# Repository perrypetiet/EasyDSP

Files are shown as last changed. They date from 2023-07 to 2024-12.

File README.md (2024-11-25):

# EasyDSP prototype_dev v0.1 development branch.
This is the EasyDSP prototype development library. In this repository you will find the hardware of the EasyDSP as well as the corresponding firmware. In this readme you will find an explanation of how to firmware functions and how to control the EasyDSP using the corresponding communication protocol. Also, you will find the PCB schematics and PCB design without the need to have KiCad and all the corresponding components on hand.

This readme will be updated to display correct and relevant information depending on the branch.

## Table of contents:
- [EasyDSP prototype\_dev v0.1 development branch.](#easydsp-prototype_dev-v01-development-branch)
  - [Table of contents:](#table-of-contents)
  - [Introduction ](#introduction-)
  - [TODO list ](#todo-list-)
  - [Controlling via BLE. ](#controlling-via-ble-)
  - [Python. ](#python-)
  - [Hardware ](#hardware-)

## Introduction 
The goal of this project is to make a cheap and easy to control module in order to do all your audio digital signal processing needs. The EasyDSP could be used for audio crossover, room correction, subwoofer tuning, using [Bass Eq](https://www.avsforum.com/threads/bass-eq-for-filtered-movies.2995212/) and much more. The goal of the project is to be able to control the EasyDSP using a Bluetooth low energy connection. When connected BLE characteristics can be used to control the EasyDSP. The basic structure of the signal processor can be explained with the following image:
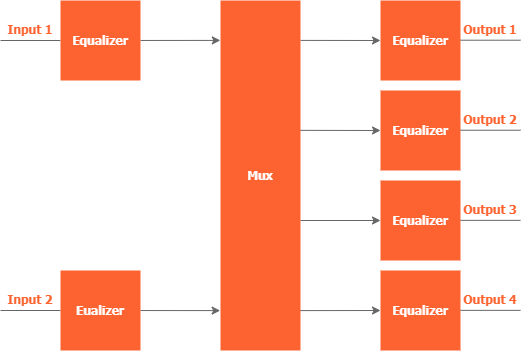
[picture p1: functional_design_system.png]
Basic DSP overview
</br></br>
The EasyDSP has two inputs and four outputs. The mux makes it possible to connect any input with any output. Every in and output has an equalizer to which five filters can be applied.</br>
The goal of the protoype is to implement the basic functioning of this system while doing it reliably. When this is achieved, functionality can be upgraded.

## TODO list 

- Make the settings store on the EEPROM. ✅
- Implement more filters (Bessel?) for better low pass and high pass.
- Maybe improve Python module for this verstion.

Things to include in next version:
- Better PCB design to improve the noise in the audio signal coming from the Bluetooth antenna (External antenna?).
- RGB status indication LED.
- Case design. (3D printable).
- Start working on GUI app for desktop to control the device.
- More functionality in firmware, more filters and gain control. And overall cleanup. 
- Thinking about serial control via USB.

## Controlling via BLE. 
Easydsp can be controlled with a BLE connection. The BLE implements two different services. The first service is a "selection" service. With this service the channel and eq number that are desired to be changed can be selected. With the channel number characteriscic you can change the channel number. With the isOutput characteristic you can select if it is an input or output channel that is selected. With the eq characteristic you can selected one of the 5 eq's per channel that you wish to change te settings of.

The EQ service implements the EQ data of the selected EQ on the selected channel. This service has characteristics to change the behaviour of the selected EQ. 

## Python. 
Included is a simple python module, easydsp.py, that can be used to control the easydsp over a BLE connection. I have also included a simple Python command line program that uses this module to control the EasyDSP.

## Hardware 
The EasyDSP is based on the ADAU1701 digital signal processor from Analog Devices. The chip is used in I2C control mode. This way, we can control the the signal processor from an external microcontroller during operation. The microcontroller used is an ESP32-S3 in the form a WROOM module to make development of the prototype hardware easier. The board and firmware have the ability to store the EQ, MUX and gain settings on an EEPROM. The EEPROM used is a 24LC128 in an MSOP package. Technically lower storage 24LC EEPROM's can also be used. In order to upload the firmware to the board, the USB connector on the PCB can be used. Firmware can also be uploaded and monitored using an external USB to UART PCB connected to the connector on the main PCB. There is an example board in the hardware folder. Following is the hardware schematic. The schematic can also be opened using KiCad.
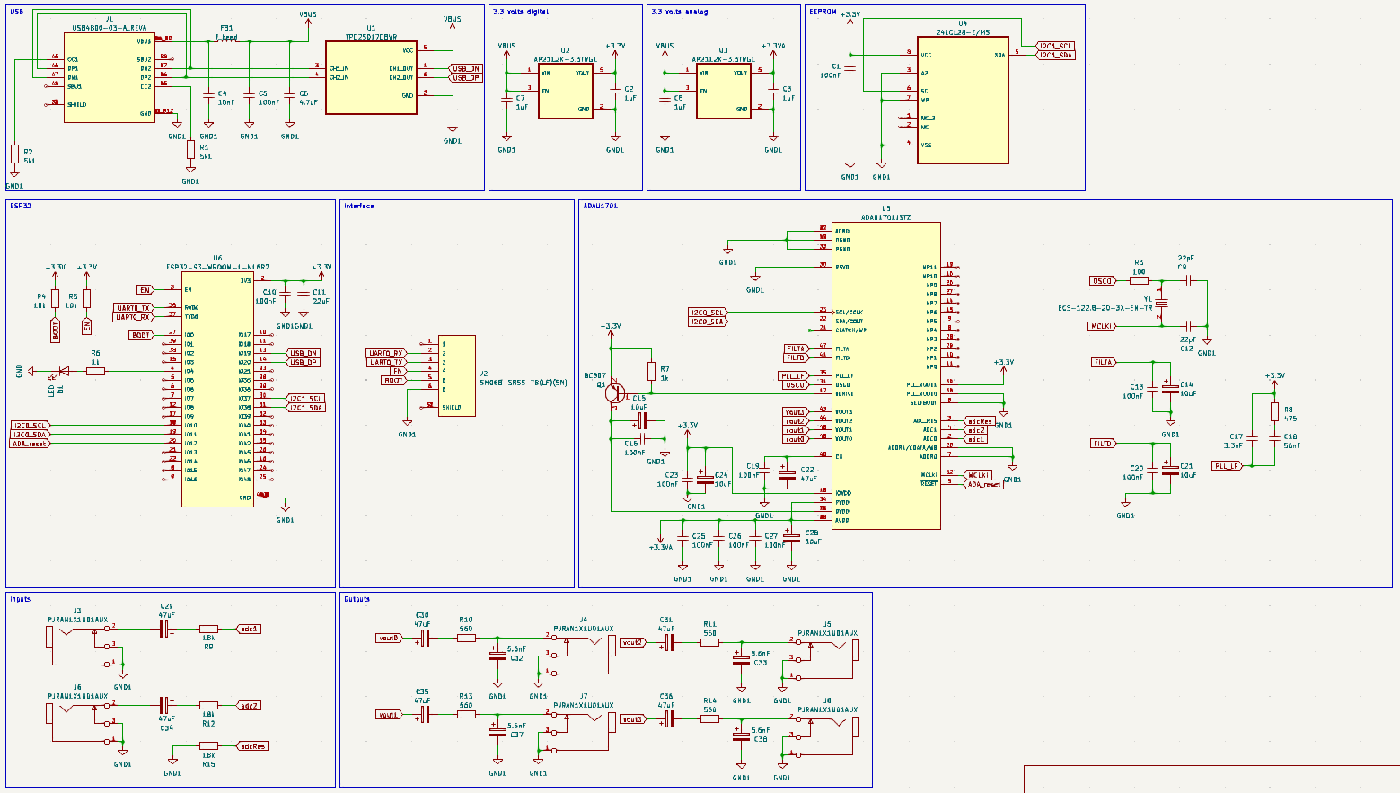
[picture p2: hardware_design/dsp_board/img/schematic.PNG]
Hardware schematic
</br></br>
The PCB fabrication files can be found in the hardware_design folder. Using these gerber and drill files you can order a PCB from a manufactorer.
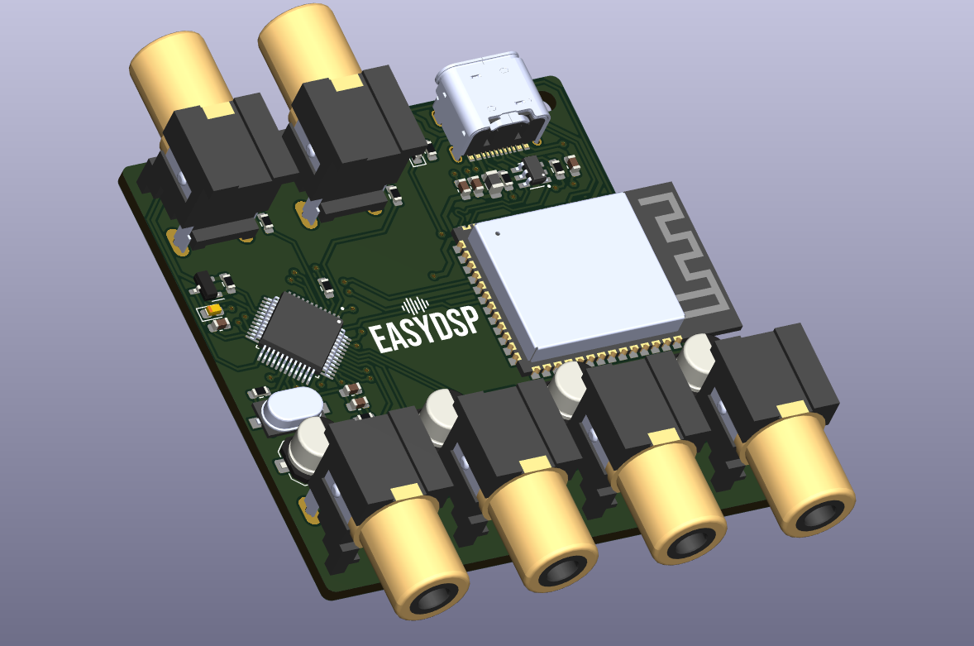
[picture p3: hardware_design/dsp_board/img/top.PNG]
PCB top
</br></br>
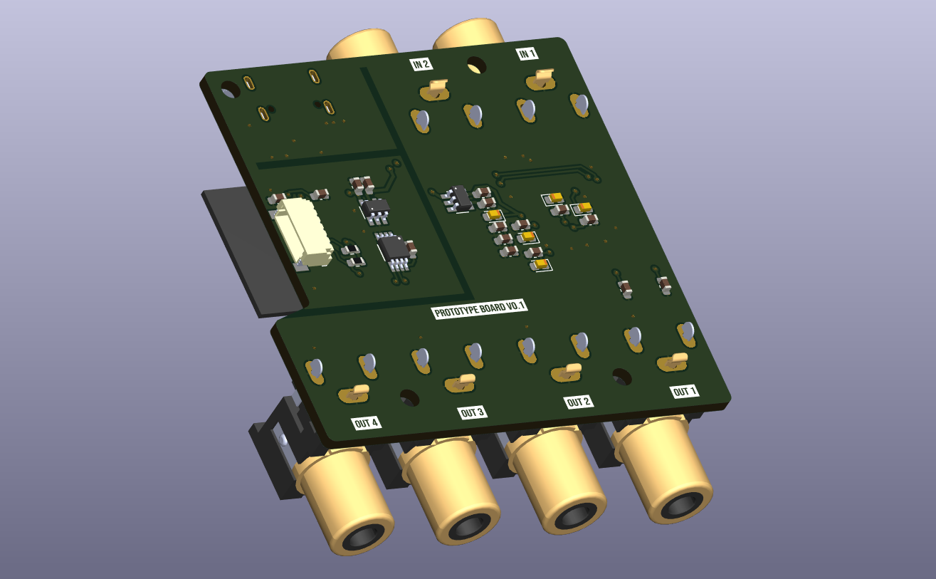
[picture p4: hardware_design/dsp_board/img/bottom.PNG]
PCB bottom
</br></br>

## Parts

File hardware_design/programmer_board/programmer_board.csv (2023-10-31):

# | Reference | Qty | Value | Footprint | DNP
1 | C1, C2 | 2 | 1uF | Capacitor_SMD:C_0603_1608Metric
2 | C3, C4 | 2 | 22pF | Capacitor_SMD:C_0603_1608Metric
3 | C5 | 1 | 10nF | Capacitor_SMD:C_0603_1608Metric
4 | C6, C8, C9 | 3 | 100nF | Capacitor_SMD:C_0603_1608Metric
5 | C7 | 1 | 4.7uF | Capacitor_SMD:C_0603_1608Metric
6 | D1 | 1 | LED | Diode_SMD:D_0603_1608Metric
7 | FB1 | 1 | f_bead | Inductor_SMD:L_0805_2012Metric
8 | J1 | 1 | SM06B-SRSS-TB(LF)(SN) | JST_SM06B-SRSS-TB(LF)(SN)
9 | J2 | 1 | USB4800-03-A_REVA | GCT_USB4800-03-A_REVA
10 | Q1, Q2 | 2 | SS8050-G | TRANS_SS8050-G
11 | R1 | 1 | 0 | Resistor_SMD:R_0603_1608Metric
12 | R2, R4 | 2 | 10k | Resistor_SMD:R_0603_1608Metric
13 | R3, R5, R6 | 3 | 5k1 | Resistor_SMD:R_0603_1608Metric
14 | S1, S2 | 2 | TL6330AF200Q | SW_TL6330AF200Q
15 | U1 | 1 | AP2112K-3.3TRG1 | SOT95P285X140-5N
16 | U2 | 1 | TPD2S017DBVR | SOT95P280X145-6N
17 | U3 | 1 | CH340G | SOIC127P600X180-16N
18 | Y1 | 1 | ECS-120-20-3X-EN-TR | XTAL_ECS-120-20-3X-EN-TR

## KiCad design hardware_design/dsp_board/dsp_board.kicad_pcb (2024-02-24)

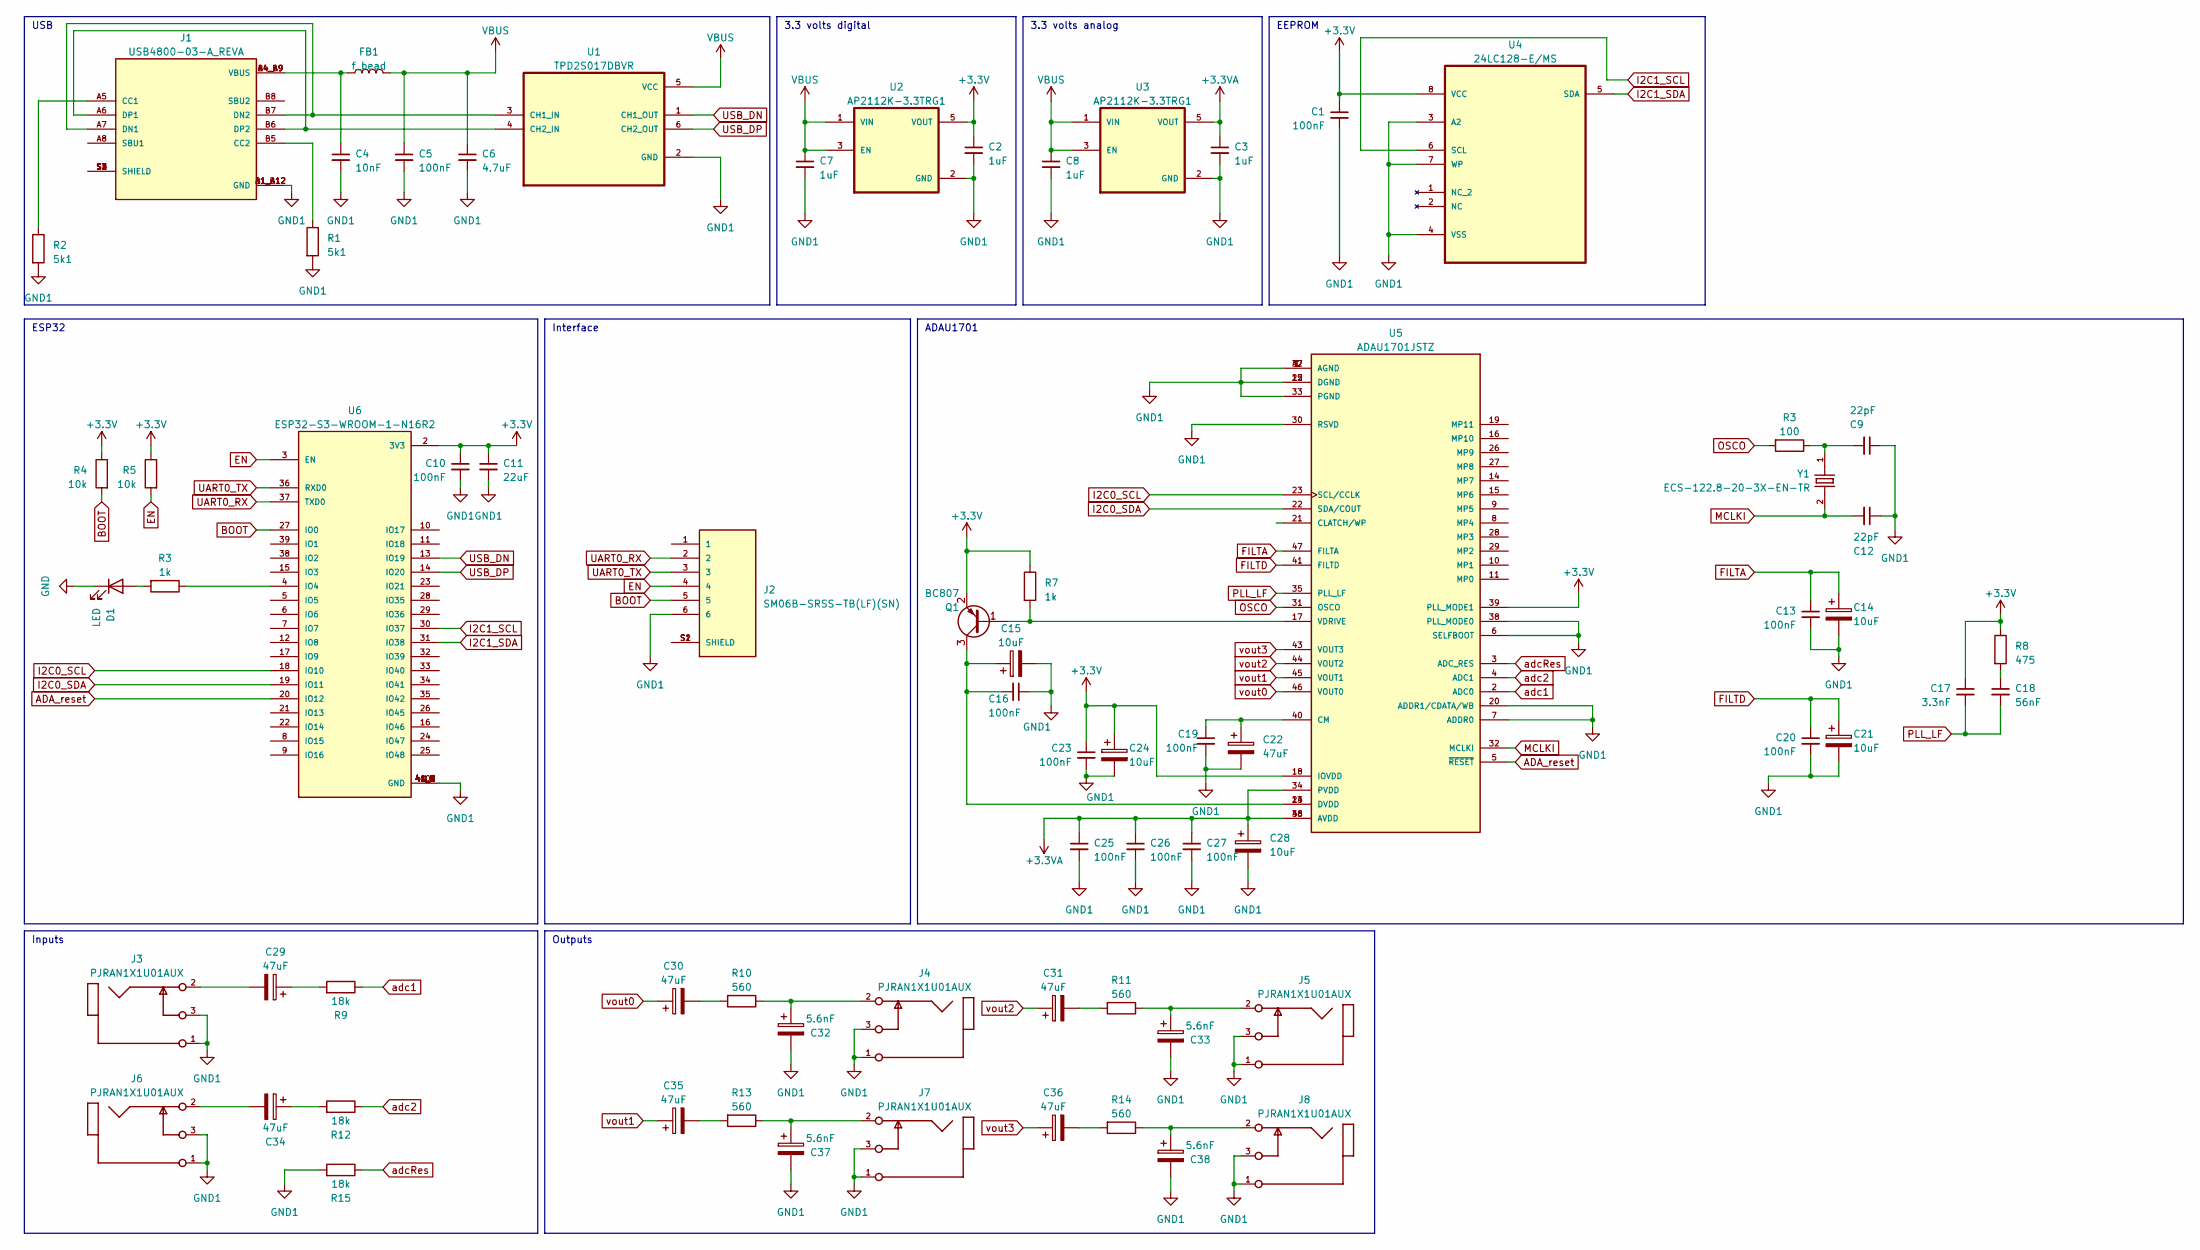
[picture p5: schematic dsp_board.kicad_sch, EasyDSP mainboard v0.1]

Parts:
C1, C5, C10, C13, C16, C19, C20, C23, C25, C26, C27: 100nF; C_0603_1608Metric
C2, C3, C7, C8: 1uF; C_0603_1608Metric
C4: 10nF; C_0603_1608Metric
C6: 4.7uF; C_0603_1608Metric
C9, C12: 22pF; C_0603_1608Metric
C11: 22uF; C_0603_1608Metric
C14, C15, C21, C24, C28: 10uF; CP_EIA-1608-08_AVX-J
C17: 3.3nF; C_0603_1608Metric
C18: 56nF; C_0603_1608Metric
C22, C29, C34: 47uF; CP_EIA-1608-08_AVX-J
C30, C31, C35, C36: 47uF; CP_Elec_5x4.5
C32, C33, C37, C38: 5.6nF; CP_EIA-1608-08_AVX-J
D1: LED; D_0603_1608Metric
FB1: f_bead; L_0805_2012Metric
J1: USB4800-03-A_REVA; GCT_USB4800-03-A_REVA; PARTREV A
J2: SM06B-SRSS-TB(LF)(SN); JST_SM06B-SRSS-TB(LF)(SN)
J3, J4, J5, J6, J7, J8: PJRAN1X1U01AUX; PJRAN1X1U01X
Q1: BC807; SOT-23
R1, R2: 5k1; R_0603_1608Metric
R3: 100; R_0603_1608Metric
R4, R5: 10k; R_0603_1608Metric
R7: 1k; R_0603_1608Metric
R8: 475; R_0603_1608Metric
R9, R12, R15: 18k; R_0603_1608Metric
R10, R11, R13, R14: 560; R_0603_1608Metric
U1: TPD2S017DBVR; SOT95P280X145-6N
U2, U3: AP2112K-3.3TRG1; SOT95P285X140-5N; PARTREV 2-2
U4: 24LC128-E/MS; SOP65P490X110-8N; MPN 24LC128-E/MS
U5: ADAU1701JSTZ; QFP50P900X900X160-48N; PARTREV C
U6: ESP32-S3-WROOM-1-N16R2; XCVR_ESP32-S3-WROOM-1-N16R2; PARTREV v1.0
Y1: ECS-122.8-20-3X-EN-TR; XTAL_ECS-122.8-20-3X-EN-TR; PARTREV 2017

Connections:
+3.3V: C1.1, C2.1, C10.1, C11.1, C17.1, C23.1, C24.1, Q1.2 (E), R4.1, R5.1, R7.1, R8.1, U2.5 (VOUT), U4.8 (VCC), U5.18 (IOVDD), U5.39 (PLL_MODE1), U6.2 (3V3)
+3.3VA: C3.1, C25.1, C26.1, C27.1, C28.1, U3.5 (VOUT), U5.34 (PVDD), U5.36 (AVDD), U5.48 (AVDD)
ADA_reset: U5.5 (~RESET), U6.20 (IO12)
BOOT: J2.5, R4.2, U6.27 (IO0)
EN: J2.4, R5.2, U6.3 (EN)
FILTA: C13.1, C14.1, U5.47 (FILTA)
FILTD: C20.1, C21.1, U5.41 (FILTD)
GND: D1.1 (K)
GND1: C1.2, C2.2, C3.2, C4.2, C5.2, C6.2, C7.2, C8.2, C9.1, C10.2, C11.2, C12.1, C13.2, C14.2, C15.2, C16.1, C19.2, C20.2, C21.2, C22.2, C23.2, C24.2, C25.2, C26.2, C27.2, C28.2, C32.2, C33.2, C37.2, C38.2, J1.A1_B12 (GND), J1.B1_A12 (GND), J2.6, J3.1, J3.3, J4.1, J4.3, J5.1, J5.3, J6.1, J6.3, J7.1, J7.3, J8.1, J8.3, R1.2, R2.2, R15.2, U1.2 (GND), U2.2 (GND), U3.2 (GND), U4.3 (A2), U4.4 (VSS), U4.7 (WP), U5.1 (AGND), U5.6 (SELFBOOT), U5.7 (ADDR0), U5.12 (DGND), U5.20 (ADDR1/CDATA/WB), U5.25 (DGND), U5.30 (RSVD), U5.33 (PGND), U5.37 (AGND), U5.38 (PLL_MODE0), U5.42 (AGND), U6.1 (GND), U6.40 (GND), U6.41_1 (GND), U6.41_2 (GND), U6.41_3 (GND), U6.41_4 (GND), U6.41_5 (GND), U6.41_6 (GND), U6.41_7 (GND), U6.41_8 (GND), U6.41_9 (GND)
I2C0_SCL: U5.23 (SCL/CCLK), U6.18 (IO10)
I2C0_SDA: U5.22 (SDA/COUT), U6.19 (IO11)
I2C1_SCL: U4.6 (SCL), U6.30 (IO37)
I2C1_SDA: U4.5 (SDA), U6.31 (IO38)
MCLKI: C12.2, U5.32 (MCLKI), Y1.2
unnamed: C4.1, FB1.1, J1.A4_B9 (VBUS), J1.B4_A9 (VBUS)
unnamed: C18.1, R8.2
unnamed: C29.1, R9.2
unnamed: C29.2, J3.2
unnamed: C30.2, R10.2
unnamed: C31.2, R11.2
unnamed: C32.1, J4.2, R10.1
unnamed: C33.1, J5.2, R11.1
unnamed: C34.1, R12.2
unnamed: C34.2, J6.2
unnamed: C35.2, R13.2
unnamed: C36.2, R14.2
unnamed: C37.1, J7.2, R13.1
unnamed: C38.1, J8.2, R14.1
unnamed: J1.A5 (CC1), R2.1
unnamed: J1.B5 (CC2), R1.1
unnamed: J1.A7 (DN1), J1.B7 (DN2), U1.3 (CH1_IN)
unnamed: J1.A6 (DP1), J1.B6 (DP2), U1.4 (CH2_IN)
unnamed: J1.S1 (SHIELD), J1.S2 (SHIELD), J1.S3 (SHIELD), J1.S4 (SHIELD)
unnamed: J2.S1 (SHIELD), J2.S2 (SHIELD)
unnamed: Q1.1 (B), R7.2, U5.17 (VDRIVE)
unnamed: C15.1, C16.2, Q1.3 (C), U5.13 (DVDD), U5.24 (DVDD)
unnamed: C19.1, C22.1, U5.40 (CM)
PLL_LF: C17.2, C18.2, U5.35 (PLL_LF)
UART0_RX: J2.2, U6.37 (TXD0)
UART0_TX: J2.3, U6.36 (RXD0)
USB_DN: U1.1 (CH1_OUT), U6.13 (IO19)
USB_DP: U1.6 (CH2_OUT), U6.14 (IO20)
VBUS: C5.1, C6.1, C7.1, C8.1, FB1.2, U1.5 (VCC), U2.1 (VIN), U2.3 (EN), U3.1 (VIN), U3.3 (EN)
adc1: R9.1, U5.2 (ADC0)
adc2: R12.1, U5.4 (ADC1)
adcRes: R15.1, U5.3 (ADC_RES)
vout0: C30.1, U5.46 (VOUT0)
vout1: C35.1, U5.45 (VOUT1)
vout2: C31.1, U5.44 (VOUT2)
vout3: C36.1, U5.43 (VOUT3)

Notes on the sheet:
Interface
Inputs
Outputs
ADAU1701
3.3 volts analog
3.3 volts digital
EEPROM
ESP32
USB

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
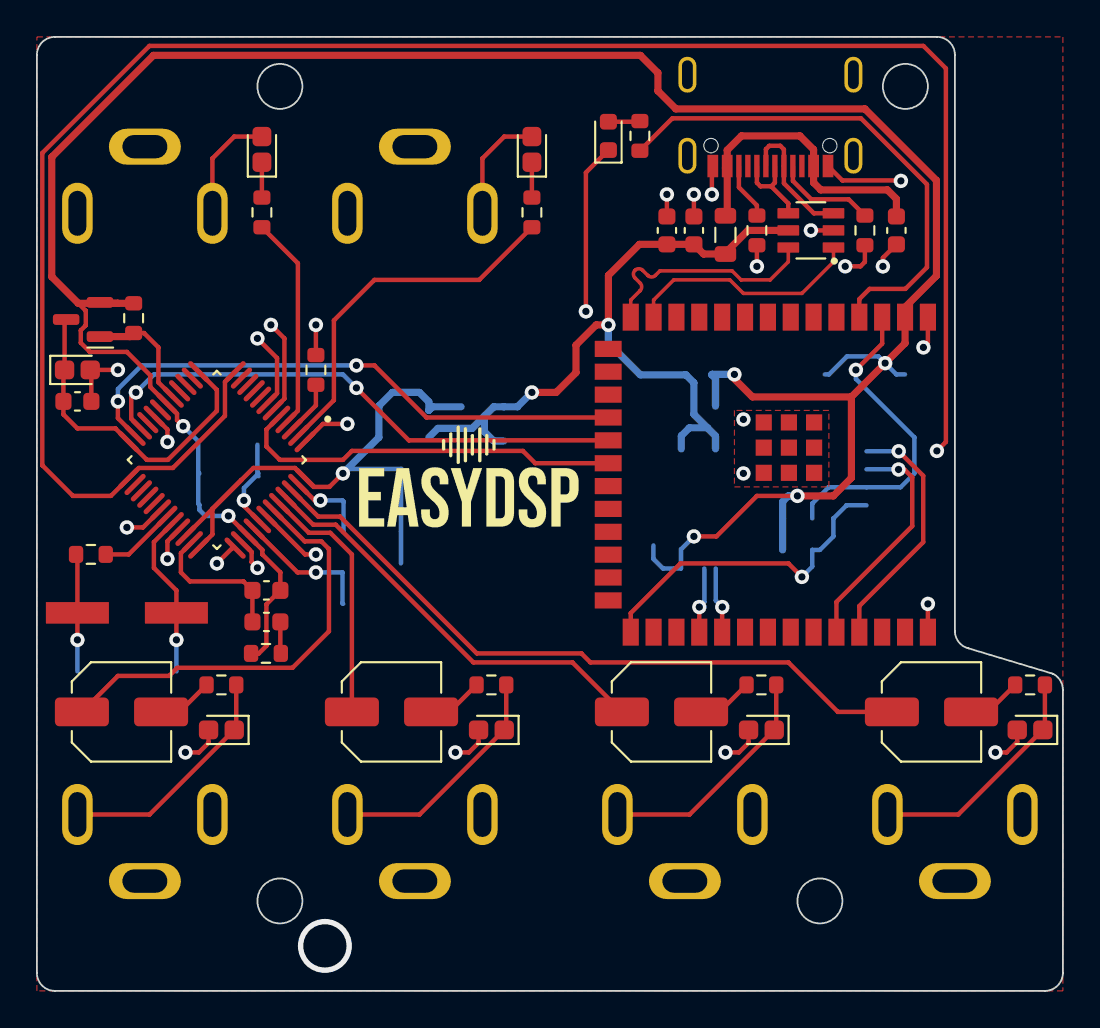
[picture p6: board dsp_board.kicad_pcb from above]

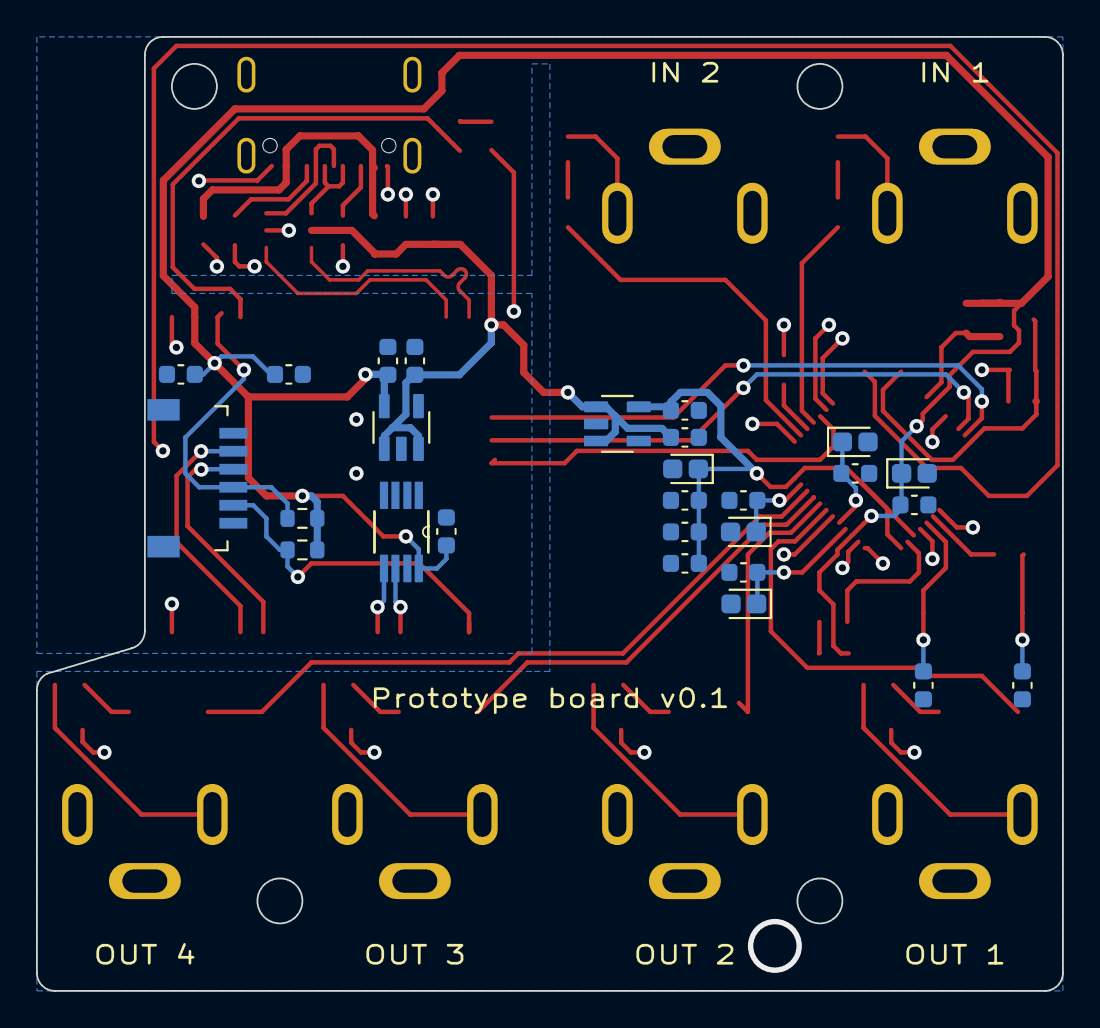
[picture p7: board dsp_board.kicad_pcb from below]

Board: 2 copper layers, 57.0 x 53.0 mm, 71 parts (27 on the bottom side), 53 nets.

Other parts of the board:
R6: 1k; R_0603_1608Metric

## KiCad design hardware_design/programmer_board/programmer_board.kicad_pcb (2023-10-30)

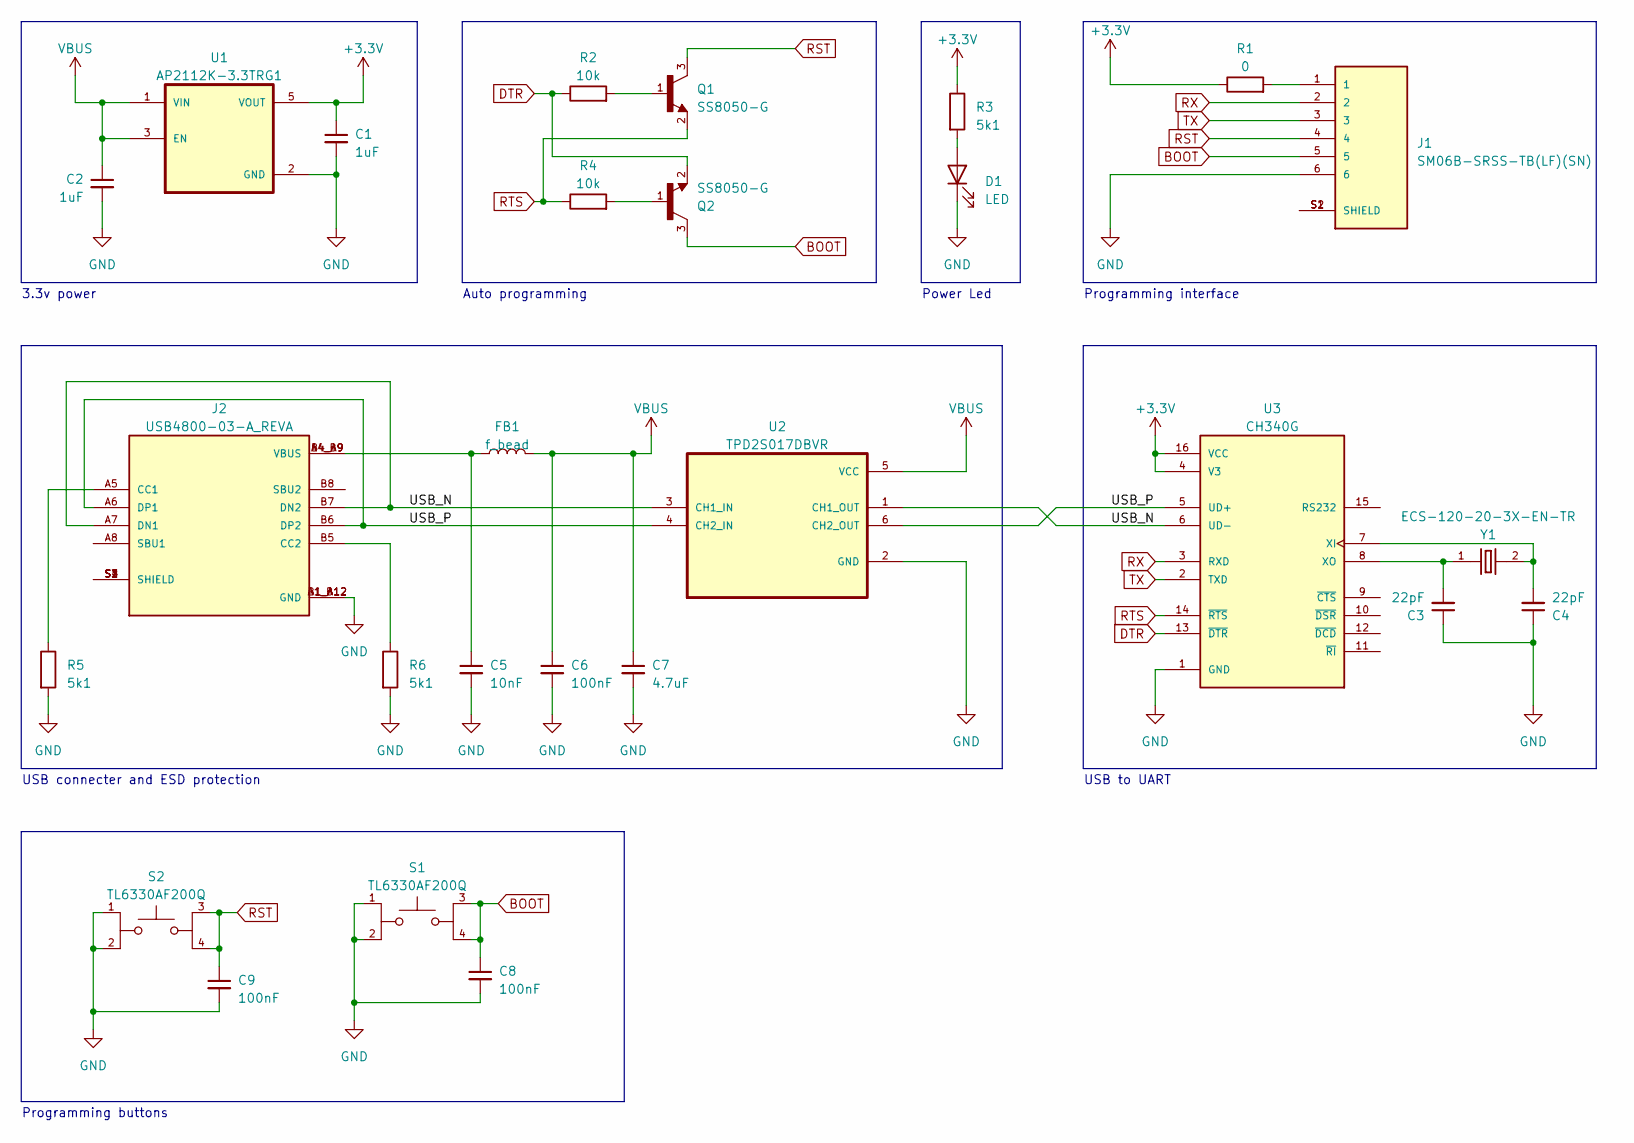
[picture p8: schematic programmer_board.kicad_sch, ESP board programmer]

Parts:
C1, C2: 1uF; C_0603_1608Metric
C3, C4: 22pF; C_0603_1608Metric
C5: 10nF; C_0603_1608Metric
C6, C8, C9: 100nF; C_0603_1608Metric
C7: 4.7uF; C_0603_1608Metric
D1: LED; D_0603_1608Metric
FB1: f_bead; L_0805_2012Metric
J1: SM06B-SRSS-TB(LF)(SN); JST_SM06B-SRSS-TB(LF)(SN)
J2: USB4800-03-A_REVA; GCT_USB4800-03-A_REVA; PARTREV A
Q1, Q2: SS8050-G; TRANS_SS8050-G; PARTREV A
R1: 0; R_0603_1608Metric
R2, R4: 10k; R_0603_1608Metric
R3, R5, R6: 5k1; R_0603_1608Metric
S1, S2: TL6330AF200Q; SW_TL6330AF200Q; PARTREV D
U1: AP2112K-3.3TRG1; SOT95P285X140-5N; PARTREV 2-2
U2: TPD2S017DBVR; SOT95P280X145-6N
U3: CH340G; SOIC127P600X180-16N; PARTREV 2G
Y1: ECS-120-20-3X-EN-TR; XTAL_ECS-120-20-3X-EN-TR; PARTREV 2017

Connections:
+3.3V: C1.1, R1.1, R3.1, U1.5 (VOUT), U3.4 (V3), U3.16 (VCC)
/USB_N: J2.A7 (DN1), J2.B7 (DN2), U2.1 (CH1_OUT), U2.3 (CH1_IN), U3.6 (UD-)
/USB_P: J2.A6 (DP1), J2.B6 (DP2), U2.4 (CH2_IN), U2.6 (CH2_OUT), U3.5 (UD+)
BOOT: C8.1, J1.5, Q2.3, S1.3, S1.4
DTR: Q2.2, R2.1, U3.13 (~DTR)
GND: C1.2, C2.2, C3.1, C4.1, C5.2, C6.2, C7.2, C8.2, C9.2, D1.1 (K), J1.6, J2.A1_B12 (GND), J2.B1_A12 (GND), R5.2, R6.2, S1.1, S1.2, S2.1, S2.2, U1.2 (GND), U2.2 (GND), U3.1 (GND)
unnamed: C5.1, FB1.1, J2.A4_B9 (VBUS), J2.B4_A9 (VBUS)
unnamed: D1.2 (A), R3.2
unnamed: J1.1, R1.2
unnamed: J1.S1 (SHIELD), J1.S2 (SHIELD)
unnamed: J2.A5 (CC1), R5.1
unnamed: J2.B5 (CC2), R6.1
unnamed: J2.S1 (SHIELD), J2.S2 (SHIELD), J2.S3 (SHIELD), J2.S4 (SHIELD)
unnamed: Q1.1, R2.2
unnamed: Q2.1, R4.2
unnamed: C4.2, U3.7 (XI), Y1.2
unnamed: C3.2, U3.8 (XO), Y1.1
RST: C9.1, J1.4, Q1.3, S2.3, S2.4
RTS: Q1.2, R4.1, U3.14 (~RTS)
RX: J1.2, U3.3 (RXD)
TX: J1.3, U3.2 (TXD)
VBUS: C2.1, C6.1, C7.1, FB1.2, U1.1 (VIN), U1.3 (EN), U2.5 (VCC)

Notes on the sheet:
3.3v power
Programming interface
Auto programming
USB to UART
USB connecter and ESD protection
Programming buttons
Power Led

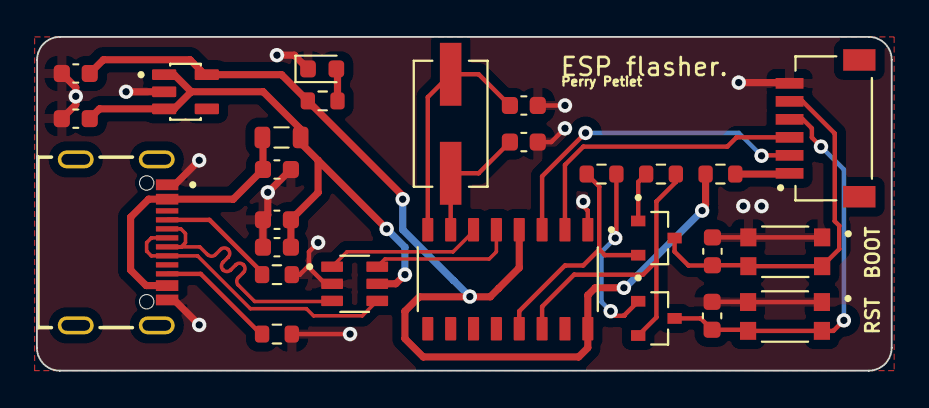
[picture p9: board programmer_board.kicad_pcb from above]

Board: 2 copper layers, 47.5 x 18.5 mm, 27 parts (0 on the bottom side), 22 nets.

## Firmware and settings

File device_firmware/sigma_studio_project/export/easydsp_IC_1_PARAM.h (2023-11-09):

/*
 * File:           C:\Users\perry\Documents\GitHub\EasyDSP\device_firmware\sigma_studio_project\export\easydsp_IC_1_PARAM.h
 *
 * Created:        Thursday, November 9, 2023 1:23:58 PM
 * Description:    easydsp:IC 1 parameter RAM definitions.
 *
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
 * This software may only be used to program products purchased from
 * Analog Devices for incorporation by you into audio products that
 * are intended for resale to audio product end users. This software
 * may not be distributed whole or in any part to third parties.
 *
 * Copyright ©2023 Analog Devices, Inc. All rights reserved.
 */
#ifndef __EASYDSP_IC_1_PARAM_H__
#define __EASYDSP_IC_1_PARAM_H__


/* Module input1_eq - Medium Size Eq*/
#define MOD_INPUT1_EQ_COUNT                            25
#define MOD_INPUT1_EQ_DEVICE                           "IC1"
#define MOD_INPUT1_EQ_ALG0_STAGE0_B0_ADDR              0
#define MOD_INPUT1_EQ_ALG0_STAGE0_B0_FIXPT             0x00800000
#define MOD_INPUT1_EQ_ALG0_STAGE0_B0_VALUE             SIGMASTUDIOTYPE_FIXPOINT_CONVERT(1)
#define MOD_INPUT1_EQ_ALG0_STAGE0_B0_TYPE              SIGMASTUDIOTYPE_FIXPOINT
#define MOD_INPUT1_EQ_ALG0_STAGE0_B1_ADDR              1
#define MOD_INPUT1_EQ_ALG0_STAGE0_B1_FIXPT             0x00000000
#define MOD_INPUT1_EQ_ALG0_STAGE0_B1_VALUE             SIGMASTUDIOTYPE_FIXPOINT_CONVERT(0)
#define MOD_INPUT1_EQ_ALG0_STAGE0_B1_TYPE              SIGMASTUDIOTYPE_FIXPOINT
#define MOD_INPUT1_EQ_ALG0_STAGE0_B2_ADDR              2
#define MOD_INPUT1_EQ_ALG0_STAGE0_B2_FIXPT             0x00000000
#define MOD_INPUT1_EQ_ALG0_STAGE0_B2_VALUE             SIGMASTUDIOTYPE_FIXPOINT_CONVERT(0)
#define MOD_INPUT1_EQ_ALG0_STAGE0_B2_TYPE              SIGMASTUDIOTYPE_FIXPOINT
#define MOD_INPUT1_EQ_ALG0_STAGE0_A0_ADDR              3
#define MOD_INPUT1_EQ_ALG0_STAGE0_A0_FIXPT             0x00000000
#define MOD_INPUT1_EQ_ALG0_STAGE0_A0_VALUE             SIGMASTUDIOTYPE_FIXPOINT_CONVERT(0)
#define MOD_INPUT1_EQ_ALG0_STAGE0_A0_TYPE              SIGMASTUDIOTYPE_FIXPOINT
#define MOD_INPUT1_EQ_ALG0_STAGE0_A1_ADDR              4
#define MOD_INPUT1_EQ_ALG0_STAGE0_A1_FIXPT             0x00000000
#define MOD_INPUT1_EQ_ALG0_STAGE0_A1_VALUE             SIGMASTUDIOTYPE_FIXPOINT_CONVERT(0)
#define MOD_INPUT1_EQ_ALG0_STAGE0_A1_TYPE              SIGMASTUDIOTYPE_FIXPOINT
#define MOD_INPUT1_EQ_ALG0_STAGE1_B0_ADDR              5
#define MOD_INPUT1_EQ_ALG0_STAGE1_B0_FIXPT             0x00800000
#define MOD_INPUT1_EQ_ALG0_STAGE1_B0_VALUE             SIGMASTUDIOTYPE_FIXPOINT_CONVERT(1)
#define MOD_INPUT1_EQ_ALG0_STAGE1_B0_TYPE              SIGMASTUDIOTYPE_FIXPOINT
#define MOD_INPUT1_EQ_ALG0_STAGE1_B1_ADDR              6
#define MOD_INPUT1_EQ_ALG0_STAGE1_B1_FIXPT             0x00000000
#define MOD_INPUT1_EQ_ALG0_STAGE1_B1_VALUE             SIGMASTUDIOTYPE_FIXPOINT_CONVERT(0)
#define MOD_INPUT1_EQ_ALG0_STAGE1_B1_TYPE              SIGMASTUDIOTYPE_FIXPOINT
#define MOD_INPUT1_EQ_ALG0_STAGE1_B2_ADDR              7
#define MOD_INPUT1_EQ_ALG0_STAGE1_B2_FIXPT             0x00000000
#define MOD_INPUT1_EQ_ALG0_STAGE1_B2_VALUE             SIGMASTUDIOTYPE_FIXPOINT_CONVERT(0)
#define MOD_INPUT1_EQ_ALG0_STAGE1_B2_TYPE              SIGMASTUDIOTYPE_FIXPOINT
#define MOD_INPUT1_EQ_ALG0_STAGE1_A0_ADDR              8
#define MOD_INPUT1_EQ_ALG0_STAGE1_A0_FIXPT             0x00000000
#define MOD_INPUT1_EQ_ALG0_STAGE1_A0_VALUE             SIGMASTUDIOTYPE_FIXPOINT_CONVERT(0)
#define MOD_INPUT1_EQ_ALG0_STAGE1_A0_TYPE              SIGMASTUDIOTYPE_FIXPOINT
#define MOD_INPUT1_EQ_ALG0_STAGE1_A1_ADDR              9
#define MOD_INPUT1_EQ_ALG0_STAGE1_A1_FIXPT             0x00000000
#define MOD_INPUT1_EQ_ALG0_STAGE1_A1_VALUE             SIGMASTUDIOTYPE_FIXPOINT_CONVERT(0)
#define MOD_INPUT1_EQ_ALG0_STAGE1_A1_TYPE              SIGMASTUDIOTYPE_FIXPOINT
#define MOD_INPUT1_EQ_ALG0_STAGE2_B0_ADDR              10
#define MOD_INPUT1_EQ_ALG0_STAGE2_B0_FIXPT             0x00800000
#define MOD_INPUT1_EQ_ALG0_STAGE2_B0_VALUE             SIGMASTUDIOTYPE_FIXPOINT_CONVERT(1)
#define MOD_INPUT1_EQ_ALG0_STAGE2_B0_TYPE              SIGMASTUDIOTYPE_FIXPOINT
#define MOD_INPUT1_EQ_ALG0_STAGE2_B1_ADDR              11
#define MOD_INPUT1_EQ_ALG0_STAGE2_B1_FIXPT             0x00000000
#define MOD_INPUT1_EQ_ALG0_STAGE2_B1_VALUE             SIGMASTUDIOTYPE_FIXPOINT_CONVERT(0)
#define MOD_INPUT1_EQ_ALG0_STAGE2_B1_TYPE              SIGMASTUDIOTYPE_FIXPOINT
#define MOD_INPUT1_EQ_ALG0_STAGE2_B2_ADDR              12
#define MOD_INPUT1_EQ_ALG0_STAGE2_B2_FIXPT             0x00000000
#define MOD_INPUT1_EQ_ALG0_STAGE2_B2_VALUE             SIGMASTUDIOTYPE_FIXPOINT_CONVERT(0)
#define MOD_INPUT1_EQ_ALG0_STAGE2_B2_TYPE              SIGMASTUDIOTYPE_FIXPOINT
#define MOD_INPUT1_EQ_ALG0_STAGE2_A0_ADDR              13
#define MOD_INPUT1_EQ_ALG0_STAGE2_A0_FIXPT             0x00000000
#define MOD_INPUT1_EQ_ALG0_STAGE2_A0_VALUE             SIGMASTUDIOTYPE_FIXPOINT_CONVERT(0)
#define MOD_INPUT1_EQ_ALG0_STAGE2_A0_TYPE              SIGMASTUDIOTYPE_FIXPOINT
#define MOD_INPUT1_EQ_ALG0_STAGE2_A1_ADDR              14
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

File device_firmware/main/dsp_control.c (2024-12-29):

/*
 * dsp_control.c
 *
 * Created: 8-11-2023 
 * Author: Perry Petiet
 * 
 * This module is used to control the DSP on a high level.
 * It initializes the sigma_dsp module and contains functions to
 * calculate the correct parameter data for eq's and muxes. the
 * functions take own defined datatypes and send the data to program
 * the sigma dsp to the sigma_dsp module which then uses the safeload
 * write functionality of the dsp chip.
 * 
 */ 
 /******************************* INCLUDES ********************************/

 #include "dsp_control.h"

 /******************************* GLOBAL VARIABLES ************************/

 static const char *TAG = "DSP_control";

 /******************************* LOCAL FUNCTIONS *************************/

 /******************************* GLOBAL FUNCTIONS ************************/

 bool init_dsp_control()
 {
  if(init_sigma_dsp(ADA_I2C_SCL_PIN, 
            ADA_I2C_SDA_PIN, 
            ADA_I2C_PORT_NUM, 
            ADA_I2C_ADDRESS, 
            ADA_GPIO_RESET) == SIGMA_DSP_INIT_SUCCESS)
  {
    return true;
  }
  return false;
 }

bool deinit_dsp_control()
{
  if(deinit_sigma_dsp() == SIGMA_DSP_DEINIT_SUCCESS)
  {
    return true;
  }
  return false;
}

bool dsp_control_mux(mux_t *mux, uint16_t sigma_dsp_address)
{
  uint8_t data[ADA_PARAM_REG_SIZE] = {0, 0, 0, 0};
  data[ADA_PARAM_REG_SIZE - 1] = mux->index;

  if(sigma_dsp_write_burst(sigma_dsp_address,
                           sizeof(data),
                           data) == SIGMA_DSP_WRITE_SUCCESS)
  {
    ESP_LOGI(TAG, "Mux write success.");
    return true;
  }
  return false;
}

bool dsp_control_eq_secondorder(equalizer_t *eq, uint16_t sigma_dsp_address)
{
  float A;
  float w0;
  float alpha;
  float gainLinear;
  float b0;
  float b1;
  float b2;
  float a0;
  float a1;
  float a2;
  float coefficients[ADA_COEFFICIENT_AMOUNT];

  A=pow(10,(eq->boost/40));       // 10^(boost/40)
  w0=2*M_PI*eq->freq/ADA_SAMPLE_FREQ; // 2*PI*freq/FS
  gainLinear = pow(10,(eq->gain/20)); // 10^(gain/20)

  switch(eq->filter_type)
  {
    case FILTER_TYPE_PEAK:
      alpha = sin(w0)/(2*eq->q);
      a0  =  1 + alpha/A;
      a1  = -2 * cos(w0);
      a2  =  1 - alpha/A;
      b0  = (1 + alpha*A) * gainLinear;
      b1  = -(2 * cos(w0)) * gainLinear;
      b2  = (1 - alpha*A) * gainLinear;
      break;
    case FILTER_TYPE_LOWSHELF:
      alpha = sin(w0)/2*sqrt((A+1/A)*(1/eq->s-1)+2);
      a0  = (A+1) + (A-1)*cos(w0) + 2*sqrt(A)*alpha;
      a1  = -2*((A-1) + (A+1)*cos(w0));
      a2  = (A+1) + (A-1)*cos(w0) - 2*sqrt(A)*alpha;
      b0  = A*((A+1) - (A-1)*cos(w0) + 2*sqrt(A)*alpha) * gainLinear;
      b1  = 2*A*((A-1) - (A+1)*cos(w0)) * gainLinear;
      b2  = A*((A+1) - (A-1)*cos(w0) - 2*sqrt(A)*alpha) * gainLinear;
      break;
    case FILTER_TYPE_HIGHSHELF:
      alpha = sin(w0)/2*sqrt((A+1/A)*(1/eq->s-1)+2);
      a0  = (A+1) - (A-1)*cos(w0) + 2*sqrt(A)*alpha;
      a1  = 2*((A-1) - (A+1)*cos(w0));
      a2  = (A+1) - (A-1)*cos(w0) - 2*sqrt(A)*alpha;
      b0  = A*((A+1) + (A-1)*cos(w0) + 2*sqrt(A)*alpha) * gainLinear;
      b1  = -2*A*((A-1) + (A+1)*cos(w0)) * gainLinear;
      b2  = A*((A+1) + (A-1)*cos(w0) - 2*sqrt(A)*alpha) * gainLinear;
      break;
    case FILTER_TYPE_LOWPASS:
      alpha = sin(w0)/(2*eq->q);
      a0  = 1 + alpha;
      a1  = -2*cos(w0);
      a2  = 1 - alpha;
      b0  = (1 - cos(w0)) * (gainLinear/2);
      b1  = (1 - cos(w0))  * gainLinear;
      b2  = (1 - cos(w0)) * (gainLinear/2);
      break;
    case FILTER_TYPE_HIGHPASS:
      alpha = sin(w0)/(2*eq->q);
      a0  = 1 + alpha;
      a1  = -2*cos(w0);
      a2  = 1 - alpha;
      b0  = (1 + cos(w0)) * (gainLinear/2);
      b1  = -(1 + cos(w0)) * gainLinear;
      b2  = (1 + cos(w0)) * (gainLinear/2);
      break;
    case FILTER_TYPE_BANDPASS:
      alpha = sin(w0) * sinh(log(2)/(2 * eq->bandwidth * w0/sin(w0)));
      a0  = 1 + alpha;
      a1  = -2*cos(w0);
      a2  = 1 - alpha;
      b0  = alpha * gainLinear;
      b1  = 0;
      b2  = -alpha * gainLinear;
      break;
    case FILTER_TYPE_BANDSTOP:
      alpha = sin(w0) * sinh(log(2)/(2 * eq->bandwidth * w0/sin(w0)));
      a0  = 1 + alpha;
      a1  = -2*cos(w0);
      a2  = 1 - alpha;
      b0  = 1 * gainLinear;
      b1  = -2*cos(w0) * gainLinear;
      b2  = 1 * gainLinear;
      break;
    default:
      // Peak:
      alpha = sin(w0)/(2*eq->q);
      a0  =  1 + alpha/A;
      a1  = -2 * cos(w0);
      a2  =  1 - alpha/A;
      b0  = (1 + alpha*A) * gainLinear;
      b1  = -(2 * cos(w0)) * gainLinear;
      b2  = (1 - alpha*A) * gainLinear;
      break;
  }
  // For Sigma DSP implementation we need to normalize all the coefficients respect to a0
  // and inverting by sign a1 and a2

  if(a0 != 0.00 && eq->state == STATE_ON)
  {
    if(eq->phase == PHASE_NON_INVERTED)
    {
      coefficients[0] = b0/a0;
      coefficients[1] = b1/a0;
      coefficients[2] = b2/a0;
      coefficients[3] = -1*a1/a0;
      coefficients[4] = -1*a2/a0;
    }
    else
    {
      coefficients[0] = -1*b0/a0;
      coefficients[1] = -1*b1/a0;
      coefficients[2] = -1*b2/a0;
      coefficients[3] = -1*a1/a0; 
      coefficients[4] = -1*a2/a0;
    }
  }
  else // (eq->state == STATE_OFF)
  {
    coefficients[0] = 1.00;
    coefficients[1] = 0;
    coefficients[2] = 0;
    coefficients[3] = 0;
    coefficients[4] = 0;
  }

  uint8_t data[ADA_COEFFICIENT_AMOUNT * 4];

  for(int i = 0; i < ADA_COEFFICIENT_AMOUNT; i++)
  {
    int32_t fixedval = (coefficients[i] * ((int32_t)1 << 23));

    data[i * 4 + 0] = (fixedval >> 24) & 0xFF;
    data[i * 4 + 1] = (fixedval >> 16) & 0xFF;
    data[i * 4 + 2] = (fixedval >>  8) & 0xFF;
    data[i * 4 + 3] = fixedval & 0xFF;
  }

  if(sigma_dsp_write_burst(sigma_dsp_address,
                           sizeof(data),
                           data              ) == SIGMA_DSP_WRITE_SUCCESS)
  {
    ESP_LOGI(TAG, "EQ write success.");
    return true;
  }
  return false;
}

 /******************************* THE END *********************************/

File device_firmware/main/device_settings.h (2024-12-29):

/*
 * device_settings.h
 *
 * Created: 9-8-2023 
 * Author: Perry Petiet
 * 
 * The device_settings library contains the settings of the device. Using
 * simple functions we can set and get settings for the inputs, outputs and
 * routing block. In and output blocks contain eq and gain. The routing 
 * block settins contain to which output(s) and input is connected.
 * 
 */ 

#ifndef DEVICE_SETTINGS_H_
#define DEVICE_SETTINGS_H_

/******************************* INCLUDES ********************************/

#include <stdio.h>
#include <stdbool.h>
#include <string.h>
#include "eeprom.h"
#include "sigma_dsp_module_data.h"
#include "crc16.h"

/******************************* DEFINES *********************************/

#define NV_STORAGE_SETTINGS_ADDRESS      0x00
#define NV_STORAGE_I2C_ADDRESS           0x50
#define NV_STORAGE_I2C_INTERFACE         1
#define NV_STORAGE_SCL_PIN               37
#define NV_STORAGE_SDA_PIN               38
#define NV_RW_SUCCESS                    1
#define NV_RW_FAILED                     0

#define NV_SETTINGS_VERSION              2

#define INIT_DEVICE_SETTINGS_SUCCESS     1
#define INIT_DEVICE_SETTINGS_FAILED      0
#define DEINIT_DEVICE_SETTINGS_SUCCESS   1
#define DEINIT_DEVICE_SETTINGS_FAILED    0

#define DEVICE_SETTINGS_DEVICE_NAME_LEN  64  
#define DEVICE_SETTINGS_INPUT_AMOUNT     2
#define DEVICE_SETTINGS_OUTPUT_AMOUNT    4
#define DEVICE_SETTINGS_INPUT_EQ_AMOUNT  5
#define DEVICE_SETTINGS_OUTPUT_EQ_AMOUNT 5

#define FILTER_TYPE_PEAK                 0
#define FILTER_TYPE_LOWSHELF             1
#define FILTER_TYPE_HIGHSHELF            2
#define FILTER_TYPE_LOWPASS              3
#define FILTER_TYPE_HIGHPASS             4
#define FILTER_TYPE_BANDPASS             5  
#define FILTER_TYPE_BANDSTOP             6

#define PHASE_NON_INVERTED               0
#define PHASE_INVERTED                   1

#define STATE_OFF                        0
#define STATE_ON                         1

#define MUX_SELECT_INPUT1                0 
#define MUX_SELECT_INPUT1_2              1
#define MUX_SELECT_INPUT2                2

/******************************* TYPEDEFS ********************************/

typedef struct
{
  float   q;
  float   s;
  float   bandwidth;
  float   boost;
  float   freq;
  float   gain;

  uint8_t filter_type;
  uint8_t phase;
  uint8_t state;

} equalizer_t;

typedef struct
{
  uint8_t  index;

} mux_t;

typedef struct
{
  equalizer_t eq[DEVICE_SETTINGS_INPUT_EQ_AMOUNT];

} input_t;

typedef struct
{
  equalizer_t eq[DEVICE_SETTINGS_OUTPUT_EQ_AMOUNT];
  mux_t       mux;
  //TODO: Add gain.

} output_t;

typedef struct
{
  uint8_t  settings_version;

  uint8_t  device_name_len;
  char     device_name[DEVICE_SETTINGS_DEVICE_NAME_LEN];
  
  input_t  inputs[DEVICE_SETTINGS_INPUT_AMOUNT];
  output_t outputs[DEVICE_SETTINGS_OUTPUT_AMOUNT];

} device_settings_t;

typedef struct
{
  device_settings_t settings;
  uint16_t          crc16;
} nv_store_t;

/******************************* LOCAL FUNCTIONS *************************/

/******************************* GLOBAL FUNCTIONS ************************/

uint8_t init_device_settings();

uint8_t deinit_device_settings();

device_settings_t* get_device_settings_address();

uint8_t device_settings_load_factory();

uint8_t device_settings_store_nv();

uint8_t device_settings_load_nv();

/******************************* THE END *********************************/

#endif /* DEVICE_SETTINGS_H_ */

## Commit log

2023-07-21 Created hardware project files
    Created hardware project files
    [dsp_board.kicad_pcb, dsp_board.kicad_sch, programmer_board.kicad_pcb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]
2023-07-21 Added footprints
    Added some footprints for development of hardware
    [24LC128-E_MS.step, ADAU1701JSTZ.step, AP2112K-3.3TRG1.step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]
2023-07-21 Started design programmer board
    [24LC128-E_MS.step, ADAU1701JSTZ.step, AP2112K-3.3TRG1.step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]
2023-07-21 Updated programmer schematic
    Started development on programmer schematic
    [programmer_board.kicad_sch]
2023-07-21 Finished programmer schematic
    Programmer schematic drawn. Review.
    [programmer_board.kicad_sch]
2023-07-21 Started programmer pcb design
    Started programmer PCB design
    [programmer_board.kicad_pcb, programmer_board.kicad_sch]
2023-07-21 Almost routed programmer board
    [programmer_board.kicad_pcb]
2023-07-24 Programmer board progress
    [programmer_board.kicad_pcb]
2023-07-24 Tested parameter header file generation
    Tested the generation of the header file from a sigmastudio project using an existing script. Working! can upload a sigmastudio project using MCUdudes library.
    [easydsp.params]
2023-08-07 Programmer board PCB
    Programmer board PCB finished.
    [programmer_board-B_Cu.gbl, programmer_board-B_Mask.gbs, programmer_board-B_Paste.gbp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]
2023-08-31 fed around with FreeRTOS tasks
    [easydsp.params, programmer_board.kicad_pcb]
2023-10-30 device settings storage
    Implemented basic library to store device settings on eeprom
    [easydsp.params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]
2023-10-31 Started devlopment sigma dsp module
    Started the development on the sigma dsp module and fixed some issues with the eeprom module.
    [programmer_board.csv]
2023-10-31 started main board design
    [dsp_board.kicad_sch]
2023-11-06 Task testing
    Played around with FreeRTOS tasks and looked over device settings code to gain ideas for improvement.
2023-11-07 Program loading implemented
    Implemented the loading of the DSP program to the ADAU1701 using i2c and the exported files from sigma studio. Also fixed memory issue with i2c. The making om i2c commands should be improved. (No for loops)
    [eeprom.c, sigma_dsp.c, sigma_dsp.h]
2023-11-08 Second order eq implemented
    [easydsp.params]
2023-11-09 Implemented MUX control
    [easydsp.params]
2023-11-09 Mux functionality added, added dsp addresses to device settings.
2023-11-10 Started PCB design
    [dsp_board.kicad_pcb, dsp_board.kicad_sch]
2023-11-16 Improved PCB
    Improved main PCB design
    [dsp_board.kicad_pcb]
2023-11-17 Mainboard progress
    Layout progress on prototype mainboard
    [dsp_board.kicad_pcb]
2023-11-19 PCB layout complete
    PCB layout and routing complete.
    [dsp_board.kicad_pcb, dsp_board.kicad_sch]
2023-11-20 Silkscreen improvements
    [dsp_board.kicad_pcb]
2023-11-20 Updated font
    [dsp_board.kicad_pcb]
2023-11-20 Disabled references
    [dsp_board.kicad_pcb]
2023-11-20 Fixed logo
    [dsp_board.kicad_pcb]
2023-11-20 Changed RCA connectors
    [dsp_board-B_Cu.gbl, dsp_board-B_Mask.gbs, dsp_board-B_Paste.gbp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]
2023-11-20 PCB concept finished
    [dsp_board.kicad_pcb]
2023-11-20 documentation update
    [dsp_board.kicad_sch]
2024-02-24 New export
    New gerber export for production. Different via's.
    [dsp_board-B_Cu.gbl, dsp_board-B_Mask.gbs, dsp_board-B_Paste.gbp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]
2024-08-17 LED driver
    Created LED driver for indicating the ble connection state.
2024-10-21 Ble terminal development
    Can now connect to BLE device from python easydsp_cmd.py
    For this prototype this will be the main control software
2024-12-22 dsp addressing easier + error led
    [device_settings.h, eeprom.c, eeprom.h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]
